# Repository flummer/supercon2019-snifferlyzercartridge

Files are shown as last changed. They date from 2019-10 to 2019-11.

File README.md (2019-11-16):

# Snifferlyzer Cartridge for the 2019 Hackaday Superconference Badge

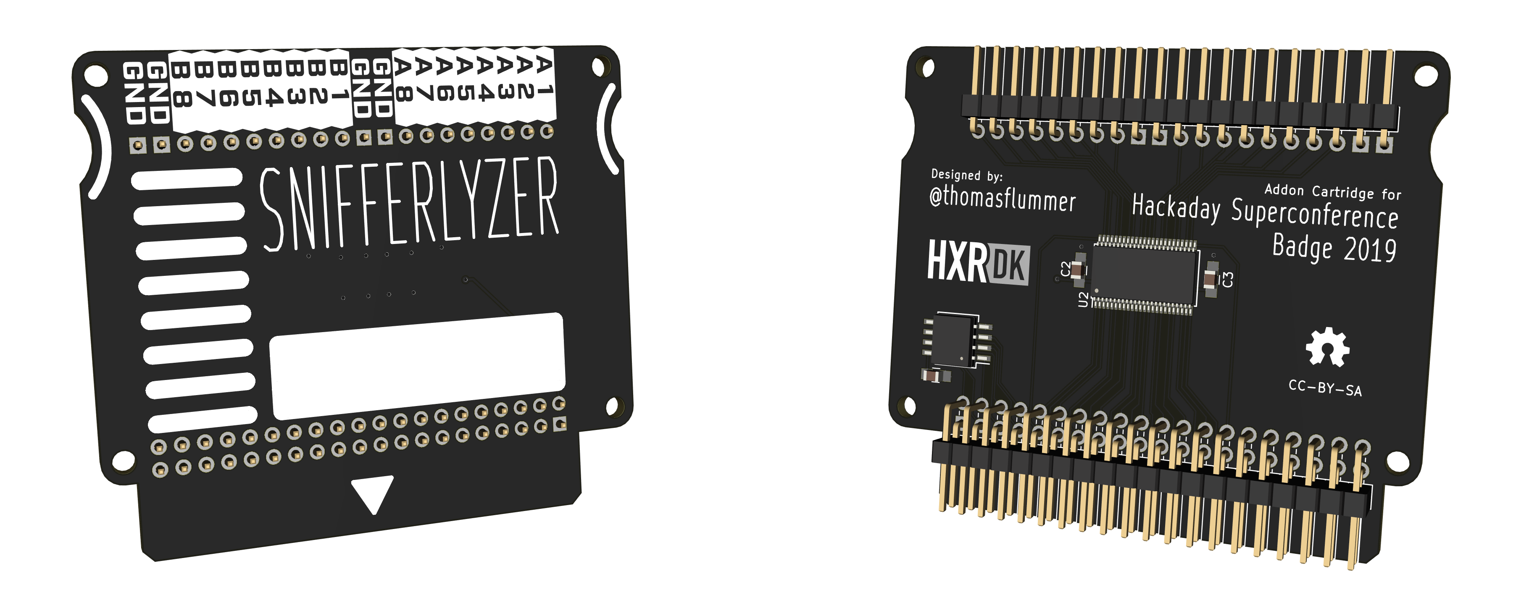
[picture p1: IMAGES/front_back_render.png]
Snifferlyzer Cartridge render


The Snifferlyzer is a simple cartridge that provides a buffered input to allow logic analyzer functionality. It's using the OnSemi 74LCX16245, that has 5V tolerant inputs and the configuration pins for the transceiver is also hooked up to the badge, allowing full control over the direction of the two 8bit banks.

This cartridge is based on the [unofficial Superconference 2019 Badge Cartridge template](https://github.com/flummer/supercon2019-cartridgetemplate) and hence include the w25q128 SPI flash and a 100nF cap in addition to the 2x20 pin angled male pin header for the badge connection. The flash allows badge configurations and firmware specific to this cartridge to be loaded from the cartridge it self making it selfcontained.

## Version 1.2 update

This updated version fixes an error in the pin connections on the cartridge connector (the two columns was flipped for some signals).

## Special note about the original version

If you want to use a PCB based on the original version with incorrect connections, it is possible to make a hardware hack on the 20x2 angeled header, where you move the pins around and bend some of them a bit, very precisely.

## License

The contents of this repository is released under the following licence:

 * the "Creative Commons Attribution-ShareAlike 4.0 International License"
   (CC BY-SA 4.0) full text of this license is included in the LICENSE file
   and a copy can also be found at
   http://creativecommons.org/licenses/by-sa/4.0/

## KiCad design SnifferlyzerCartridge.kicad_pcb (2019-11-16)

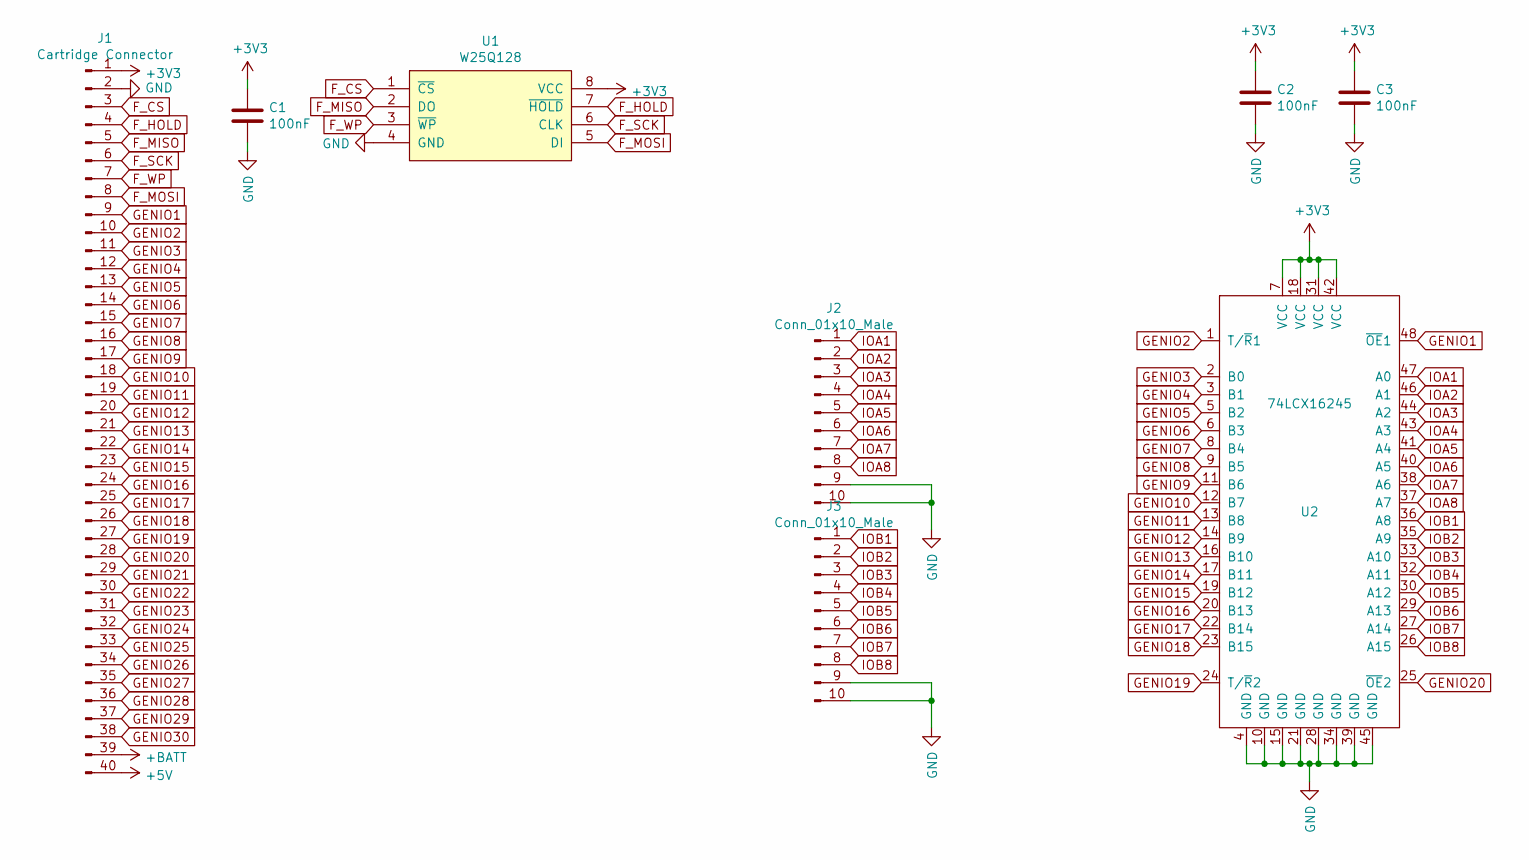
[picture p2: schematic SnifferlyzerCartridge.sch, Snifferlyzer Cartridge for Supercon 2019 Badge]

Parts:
C1, C2, C3: 100nF; C_0805_HandSoldering
J1: Cartridge Connector; Supercon_Cartridge_40pin_Connector
J2, J3: Conn_01x10_Male; Pin_Header_Angled_1x10_Pitch2.54mm
U1: W25Q128; SO-8_5.3x6.2mm_Pitch1.27mm
U2: 74LCX16245; TSSOP-48_6.1x12.5mm_Pitch0.5mm

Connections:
+3V3: C1.1, C2.1, C3.1, J1.1, U1.8 (VCC), U2.7 (VCC), U2.18 (VCC), U2.31 (VCC), U2.42 (VCC)
+5V: J1.40
+BATT: J1.39
F_CS: J1.3, U1.1 (~CS)
F_HOLD: J1.4, U1.7 (~HOLD)
F_MISO: J1.5, U1.2 (DO)
F_MOSI: J1.8, U1.5 (DI)
F_SCK: J1.6, U1.6 (CLK)
F_WP: J1.7, U1.3 (~WP)
GENIO1: J1.9, U2.48 (~OE~1)
GENIO2: J1.10, U2.1 (T/~R~1)
GENIO3: J1.11, U2.2 (B0)
GENIO4: J1.12, U2.3 (B1)
GENIO5: J1.13, U2.5 (B2)
GENIO6: J1.14, U2.6 (B3)
GENIO7: J1.15, U2.8 (B4)
GENIO8: J1.16, U2.9 (B5)
GENIO9: J1.17, U2.11 (B6)
GENIO10: J1.18, U2.12 (B7)
GENIO11: J1.19, U2.13 (B8)
GENIO12: J1.20, U2.14 (B9)
GENIO13: J1.21, U2.16 (B10)
GENIO14: J1.22, U2.17 (B11)
GENIO15: J1.23, U2.19 (B12)
GENIO16: J1.24, U2.20 (B13)
GENIO17: J1.25, U2.22 (B14)
GENIO18: J1.26, U2.23 (B15)
GENIO19: J1.27, U2.24 (T/~R~2)
GENIO20: J1.28, U2.25 (~OE~2)
GENIO21: J1.29
GENIO22: J1.30
GENIO23: J1.31
GENIO24: J1.32
GENIO25: J1.33
GENIO26: J1.34
GENIO27: J1.35
GENIO28: J1.36
GENIO29: J1.37
GENIO30: J1.38
GND: C1.2, C2.2, C3.2, J1.2, J2.9, J2.10, J3.9, J3.10, U1.4 (GND), U2.4 (GND), U2.10 (GND), U2.15 (GND), U2.21 (GND), U2.28 (GND), U2.34 (GND), U2.39 (GND), U2.45 (GND)
IOA1: J2.1, U2.47 (A0)
IOA2: J2.2, U2.46 (A1)
IOA3: J2.3, U2.44 (A2)
IOA4: J2.4, U2.43 (A3)
IOA5: J2.5, U2.41 (A4)
IOA6: J2.6, U2.40 (A5)
IOA7: J2.7, U2.38 (A6)
IOA8: J2.8, U2.37 (A7)
IOB1: J3.1, U2.36 (A8)
IOB2: J3.2, U2.35 (A9)
IOB3: J3.3, U2.33 (A10)
IOB4: J3.4, U2.32 (A11)
IOB5: J3.5, U2.30 (A12)
IOB6: J3.6, U2.29 (A13)
IOB7: J3.7, U2.27 (A14)
IOB8: J3.8, U2.26 (A15)

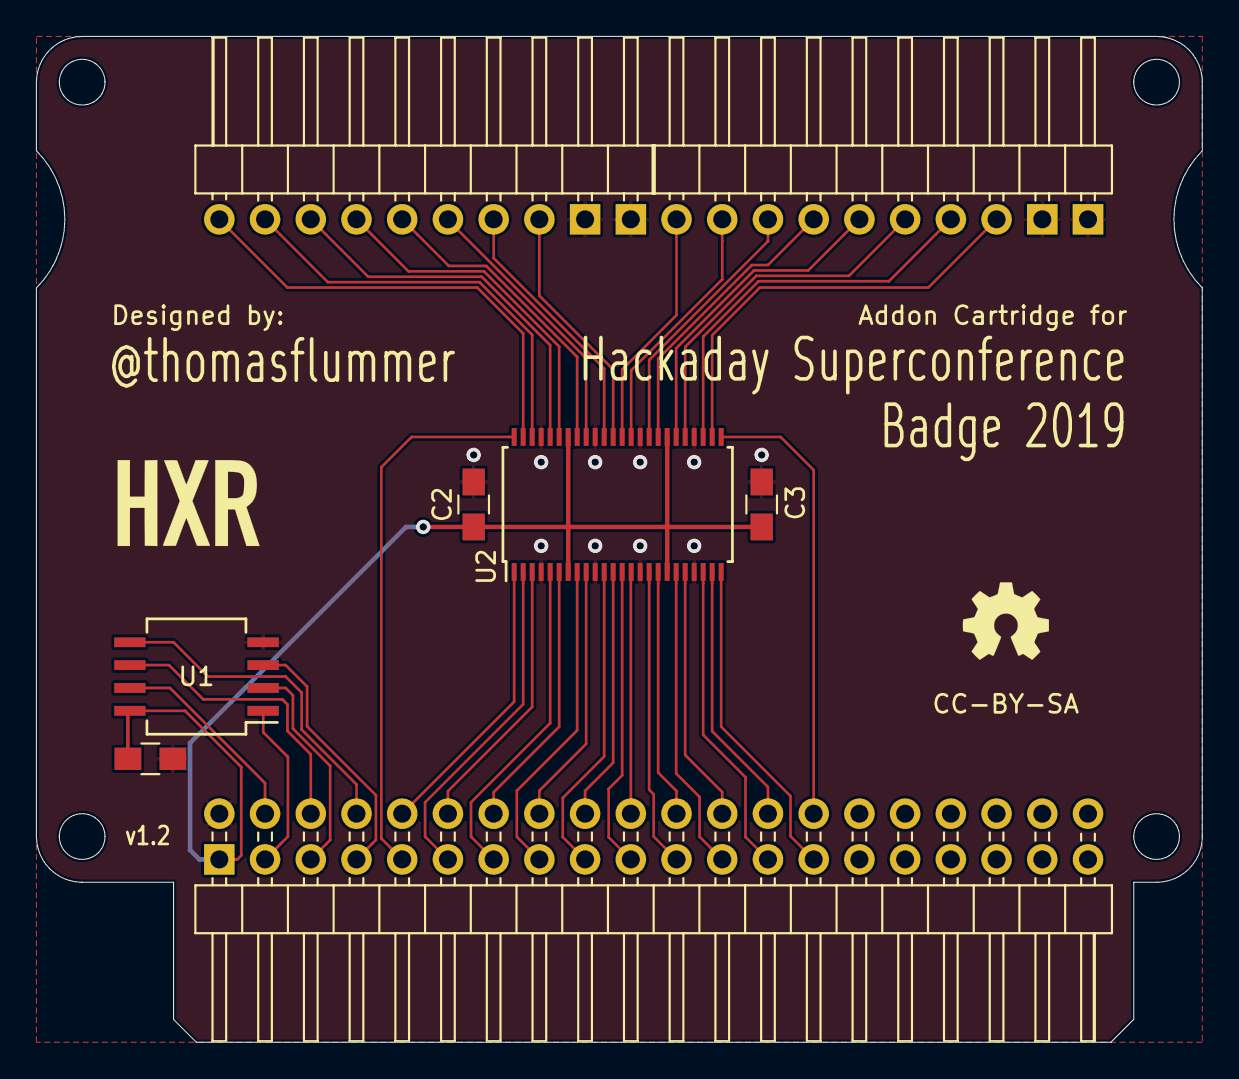
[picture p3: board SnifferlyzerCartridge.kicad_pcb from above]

Board: 2 copper layers, 64.8 x 55.9 mm, 8 parts (0 on the bottom side), 44 nets.

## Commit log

2019-10-26 Renamed template files and updated README
    [SnifferlyzerCartridge.kicad_pcb, SnifferlyzerCartridge.sch]
2019-10-26 First design of the Snifferlyzer cartridge
    Also updated:
    - README
    - Render image
    - .gitignore
    [SnifferlyzerCartridge.kicad_pcb, SnifferlyzerCartridge.sch]
2019-10-29 Updated README and gerber export settings
    [SnifferlyzerCartridge.kicad_pcb]
2019-11-16 Fixed error in cartridge connector pin assignments
    Updated to version 1.2
    [SnifferlyzerCartridge.kicad_pcb, SnifferlyzerCartridge.sch]
